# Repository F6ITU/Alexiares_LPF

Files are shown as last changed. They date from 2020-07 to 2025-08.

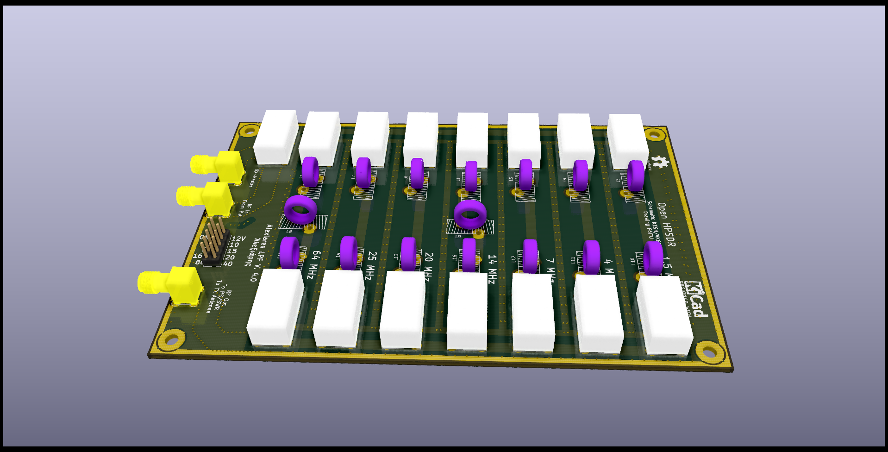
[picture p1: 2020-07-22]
images/LPF Up.png

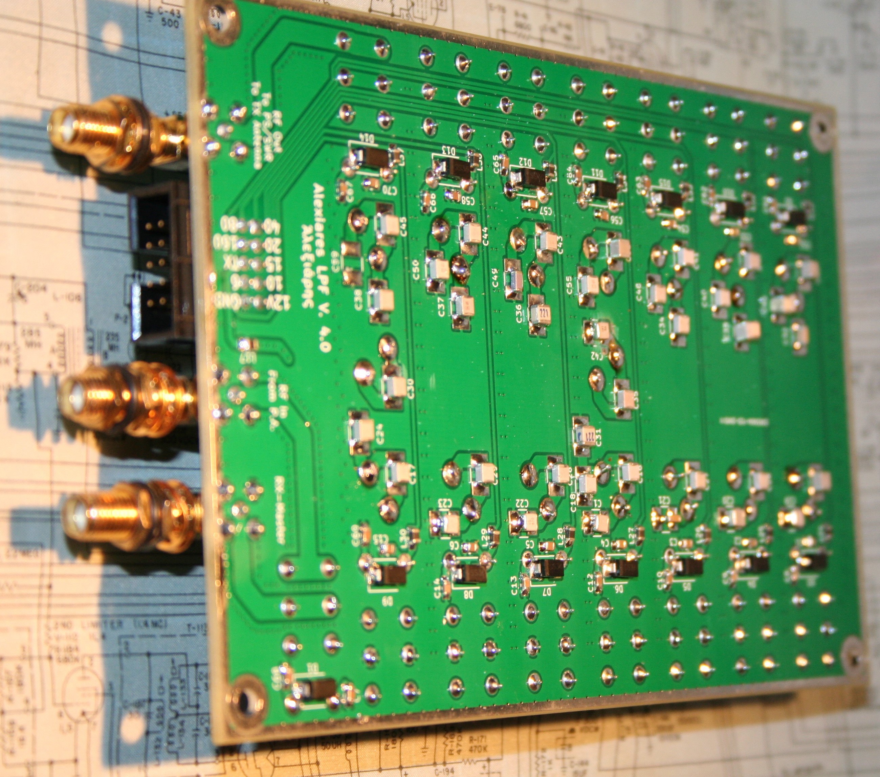
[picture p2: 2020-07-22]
images/IMG_8970.JPG

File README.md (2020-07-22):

# Alexiares_LPF
This repository contains the up to date version of the OpenHPSDR Low Pass Filter project(Alexiares frontend). 

**Important notice** : please check the "Branch" pull-down menu to see the different versions of the pcb

This work is protected by the TAPR Open Hardware Licence https://www.tapr.org/ohl.html

Original work by Graham Haddock, KE9H and Phil Harman, VK6APH.

3D image of the board are stored in the "images" folder (3D and pcb planes)

This folder also include "real life" pictures of the board, Vector Analyzer capture of the filter's characteristics and a pdf file of the schematic

Board's dimensions 10x15cm , 4 layers

So far, the Alex project under Kicad contains: 

AlexI2C

Alexandrie 

Alexiares_Coax_Out

Alexiares_HPF

Alexiares_LPF (this one)

Mentor

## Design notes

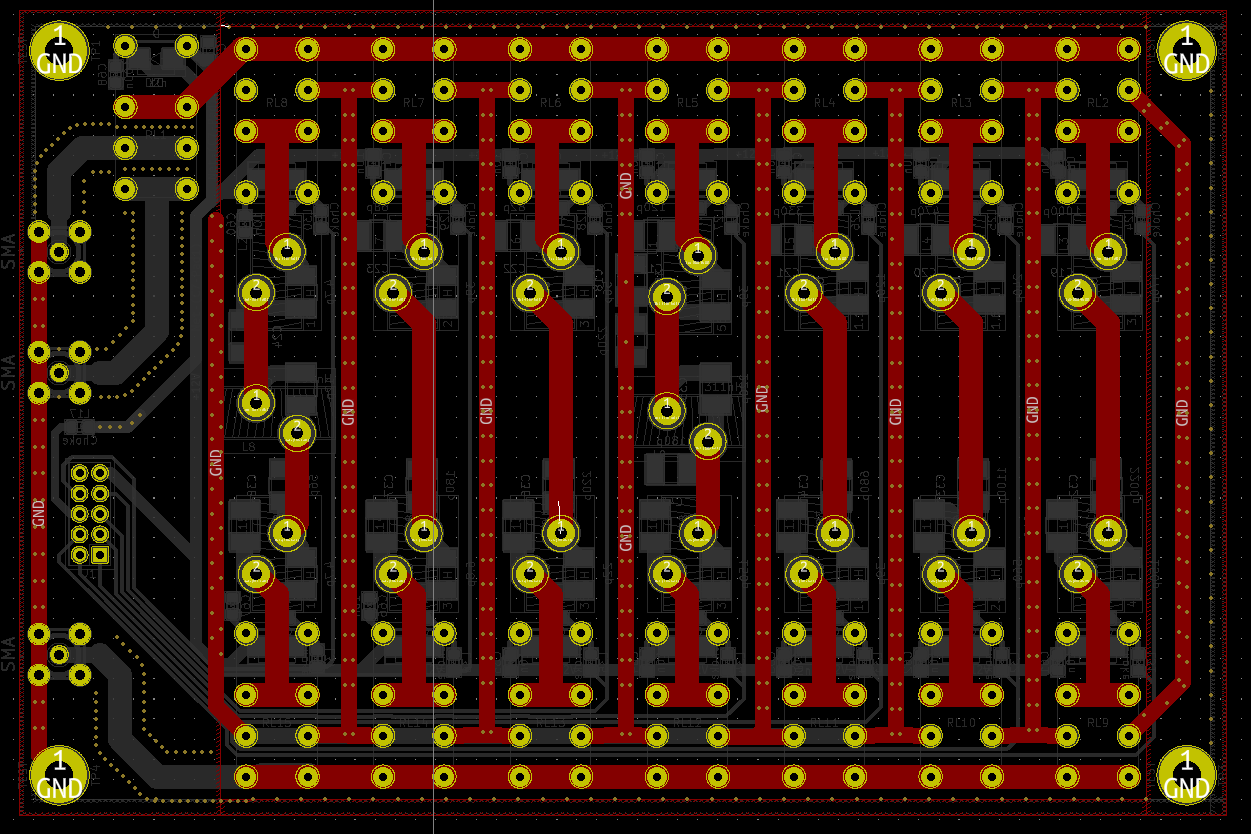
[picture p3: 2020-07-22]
images/dessus pistes.PNG

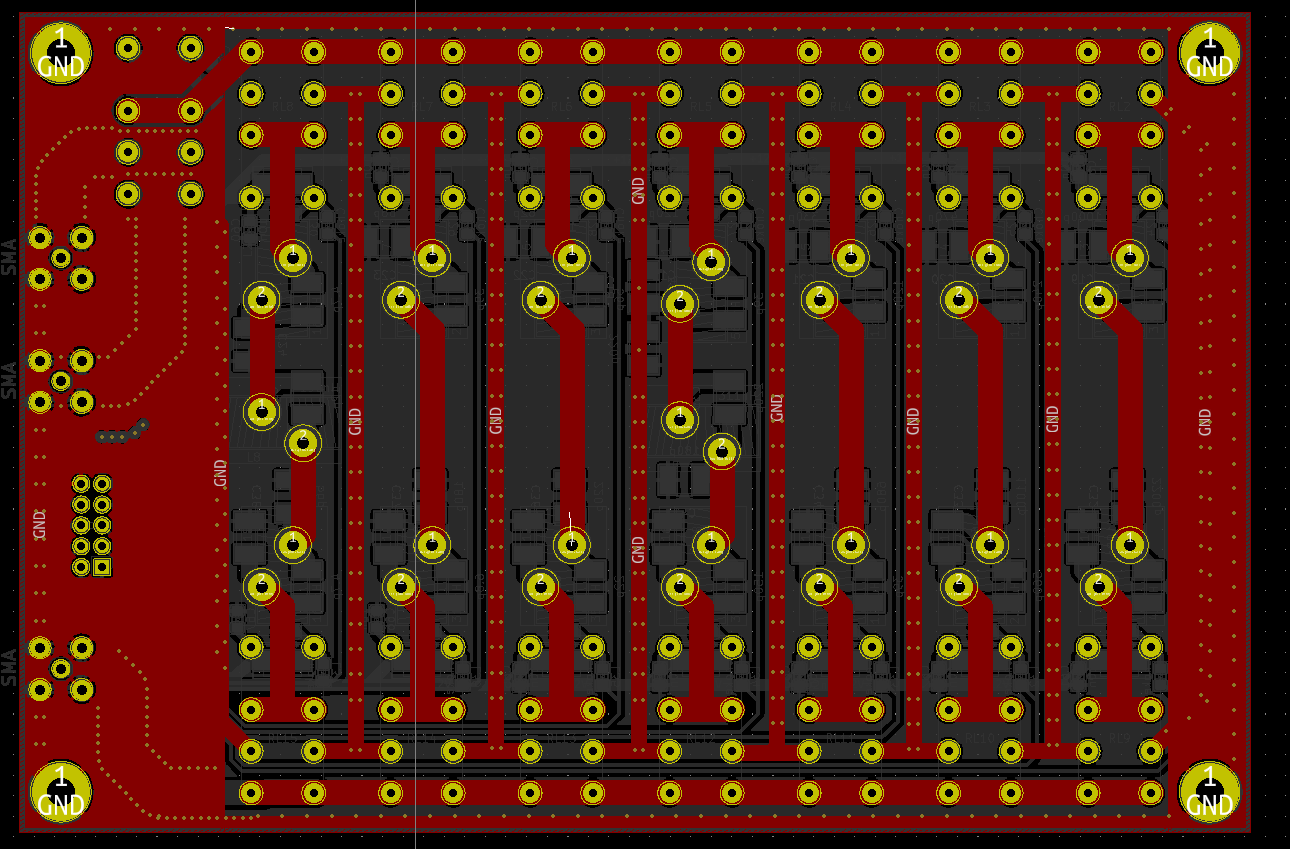
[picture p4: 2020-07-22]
images/dessus avec plan de masse.PNG

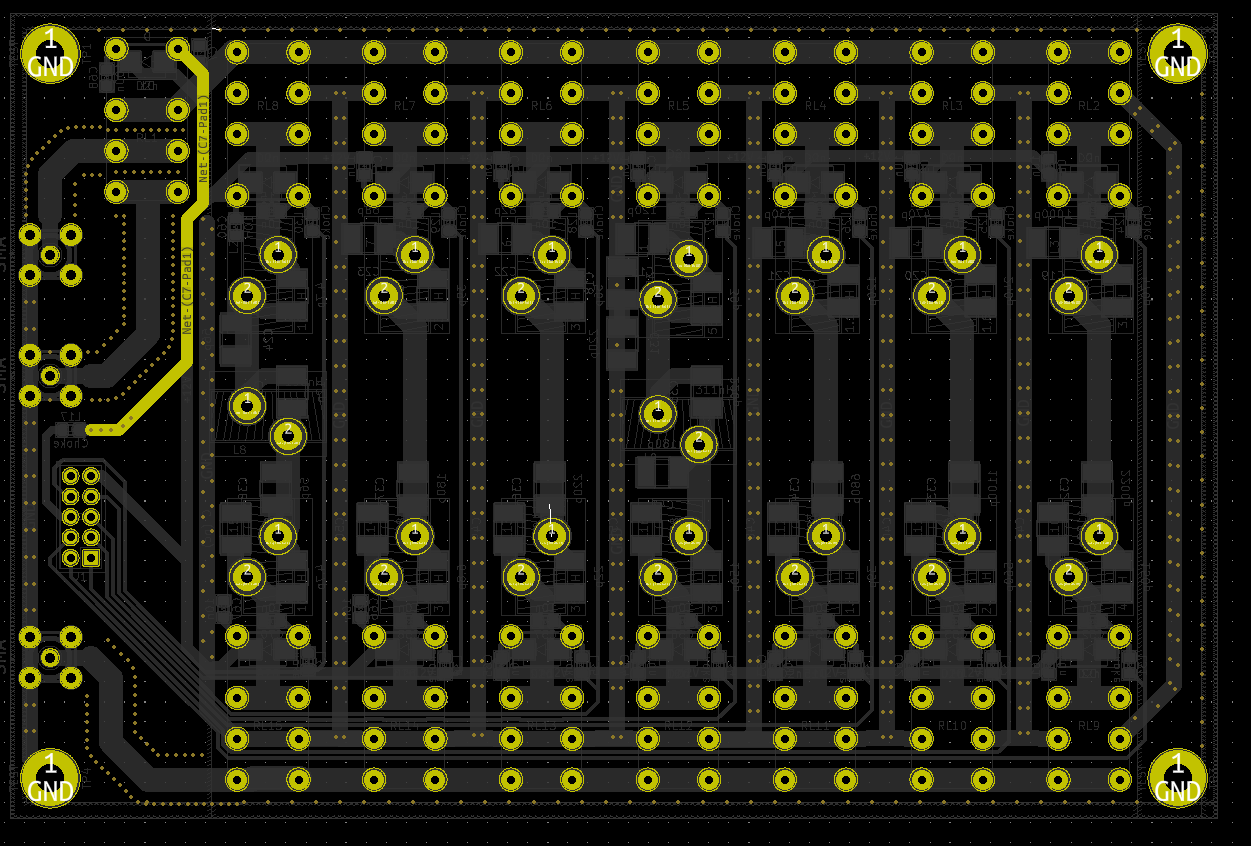
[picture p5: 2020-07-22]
images/layer 1TX-RX.PNG

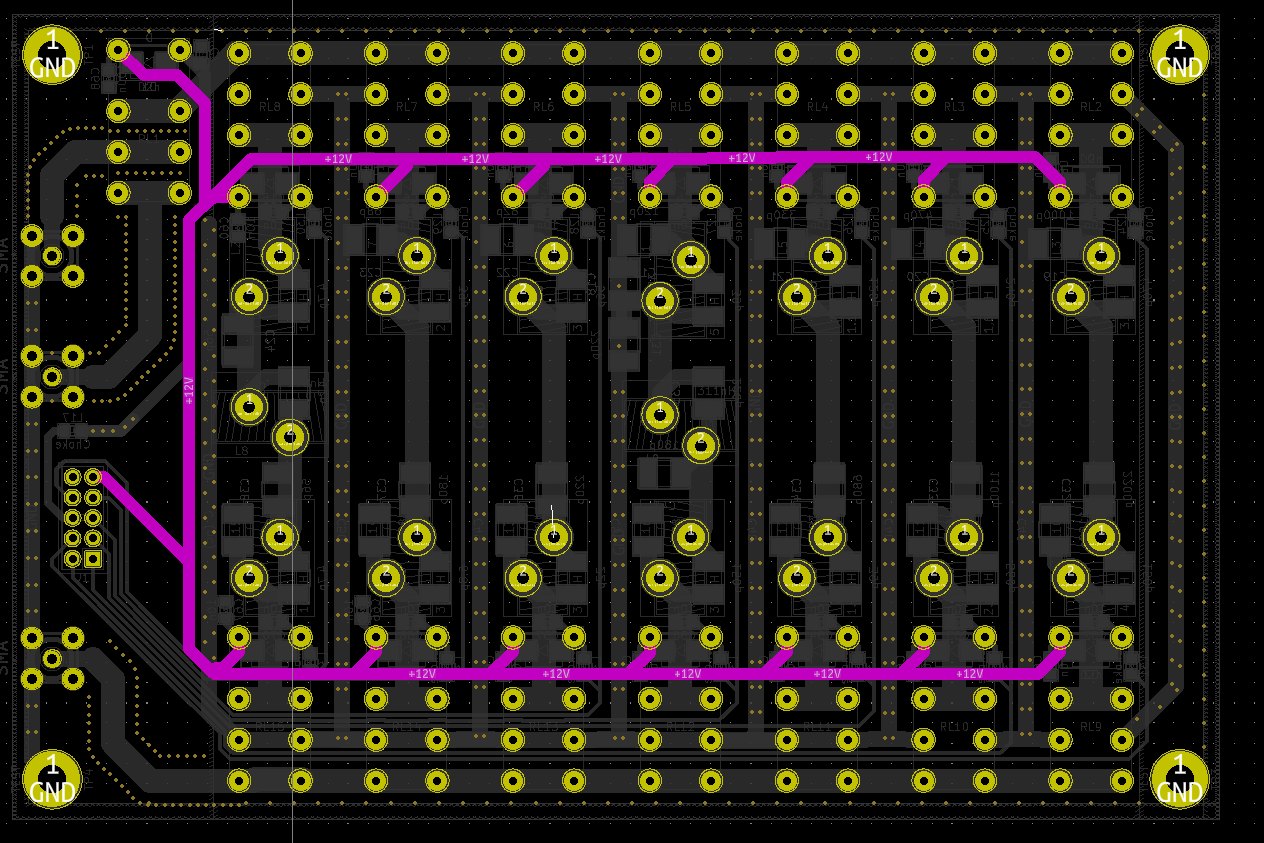
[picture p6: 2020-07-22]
images/layer 12V.PNG

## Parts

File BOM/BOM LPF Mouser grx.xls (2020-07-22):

Component Count: |  | 134
Ref | Qty | Value | Footprint | Manufacturer | Type | Vendor | Reference | Complement
C1-C10,C12-C15,C52-C54,C56-C58,C60-C67,C70 | 29 | 10n | Capacitor_SMD:C_0805_2012Metric_Pad1.15x1.40mm_HandSolder | Wurth Elektronik | MLCC | Mouser | 710-885012207092
C19 |  | 1000p | Johanson | johanson 1812 | MLCC 500V | Mouser | 501S43N102JV4E
C49 | 1 | 100p | Vishay HiFreq 1111 MLCC | Vishay Vitramon | MLCC 500V | Mouser | VJ1111D101JXLAJ
C33 | 1 | 1100p | Vishay HiFreq 1111 MLCC | Vishay Vitramon | MLCC 500V | Mouser | VJ1111D102KXDAT | VJ1111D101JXLAJ
C46 | 1 | 1100p | Vishay HiFreq 1111 MLCC | Vishay Vitramon | MLCC 500V | Mouser | VJ1111D102KXDAT | VJ1111D101JXLAJ
C11 | 1 | 120p | Vishay HiFreq 1111 MLCC | Vishay Vitramon | MLCC 500V | Mouser | VJ1111D121KXGAT
C27 | 1 | 120p | Vishay HiFreq 1111 MLCC | Vishay Vitramon | MLCC 500V | Mouser | VJ1111D121KXGAT
C30 | 1 | 12p | Vishay HiFreq 1111 MLCC | Vishay Vitramon | MLCC 500V | Mouser | VJ1111D120GLGQJ
C39 | 1 | 150p | Vishay HiFreq 1111 MLCC | Vishay Vitramon | MLCC 500V | Mouser | VJ1111D151GXLQJ
C51 | 1 | 150p | Vishay HiFreq 1111 MLCC | Vishay Vitramon | MLCC 500V | Mouser | VJ1111D151GXLQJ
C37 | 1 | 180p | Vishay HiFreq 1111 MLCC | Vishay Vitramon | MLCC 500V | Mouser | VJ1111D181JXLAJ
C42 | 1 | 180p | Vishay HiFreq 1111 MLCC | Vishay Vitramon | MLCC 500V | Mouser | VJ1111D181JXLAJ
C32 | 1 | 2200p | Johanson | Johanson 1812 | MLCC 1000V | Mouser | 102S43N222KV4E
C31 | 1 | 220p | Vishay HiFreq 1111 MLCC | Vishay Vitramon | MLCC 500V | Mouser | VJ1111D221JXLAJ
C35 | 1 | 220p | Vishay HiFreq 1111 MLCC | Vishay Vitramon | MLCC 500V | Mouser | VJ1111D221JXLAJ
C36 | 1 | 220p | Vishay HiFreq 1111 MLCC | Vishay Vitramon | MLCC 500V | Mouser | VJ1111D221JXLAJ
C43 | 1 | 22p | Vishay HiFreq 1111 MLCC | Vishay Vitramon | MLCC 500V | Mouser | VJ1111D220GLLQJ
C26 | 1 | 240p | Vishay HiFreq 1111 MLCC | Vishay Vitramon | MLCC 500V | Mouser | VJ1111D241JXLAJ
C21 | 1 | 330p | Vishay HiFreq 1111 MLCC | Vishay Vitramon | MLCC 500V | Mouser | VJ1111D331JXLAJ
C48 | 1 | 390p | Vishay HiFreq 1111 MLCC | Vishay Vitramon | MLCC 500V | Mouser | VJ1111D391KXLAJ
C16 | 1 | 39p | Vishay HiFreq 1111 MLCC | Vishay Vitramon | MLCC 500V | Mouser | VJ1111D390JXLAJ
C18 | 1 | 39p | Vishay HiFreq 1111 MLCC | Vishay Vitramon | MLCC 500V | Mouser | VJ1111D390JXLAJ
C29 | 1 | 39p | Vishay HiFreq 1111 MLCC | Vishay Vitramon | MLCC 500V | Mouser | VJ1111D390JXLAJ
C41 | 1 | 39p | Vishay HiFreq 1111 MLCC | Vishay Vitramon | MLCC 500V | Mouser | VJ1111D390JXLAJ
C17,C45 | 2 | 4.7p | Vishay HiFreq 1111 MLCC | Vishay Vitramon | MLCC 500V | Mouser | VJ1111D4R7BXLQJ
C20,C25 | 2 | 470p | Vishay HiFreq 1111 MLCC | Vishay Vitramon | MLCC 500V | Mouser | VJ1111D471KXLAJ
C47 | 1 | 560p | Johanson | Johanson 1210 | MLCC 500V | Mouser | 501S41N561KV4E
C24,C28,C38 | 3 | 56p | Vishay HiFreq 1111 MLCC | Vishay Vitramon | MLCC 500V | Mouser | VJ1111D560GXLQJ
C44 | 1 | 6.8p | Vishay HiFreq 1111 MLCC | Vishay Vitramon | MLCC 500V | Mouser | VJ1111D6R8BXGQJ
C34 | 1 | 680p | Johanson | johanson 1210 | MLCC 1000V | Mouser | 102S41N681KV4E
C23,C40 | 2 | 68p | Vishay HiFreq 1111 MLCC | Vishay Vitramon | MLCC 500V | Mouser | VJ1111D680GXLQJ
C22,C50 | 2 | 82p | Vishay HiFreq 1111 MLCC | Vishay Vitramon | MLCC 500V | Mouser | VJ1111D820GXGQJ
C55 | 1 | 82p | Capacitor_SMD:C_0805_2012Metric_Pad1.15x1.40mm_HandSolder | Wurth Elektronik | MLCC | Mouser | VJ1111D820GXGQJ
C59 | 0 | C (nc) | ATC_B:ATC_500_HandSoldering |  |  | DNI | DNI
C68 | 1 | 100n | Capacitor_SMD:C_0805_2012Metric_Pad1.15x1.40mm_HandSolder | Wurth Elektronik | MLCC | Mouser | 710-885012207098
D1-D15 | 15 | D | Diode_SMD:D_SMB | Comchip | Schottky SS24 (DO214) | Mouser | 750-SS24B-HF
J1 | 1 | Conn_02x05_Counter_Clockwise | Connector_PinHeader_2.54mm:PinHeader_2x05_P2.54mm_Vertical
L4 | 1 | 1,66uH | T50:T50_V_THT | Amidon | T68-2 | kitsandparts.com
L5 | 2 | 1.18uH | T50:T50_V_THT | Amidon | T68-2 | kitsandparts.com
L12 | 2 | 1.36uH | T50:T50_V_THT | Amidon | T68-2 | kitsandparts.com
L2,L15 | 2 | 169nH | T50:T50_V_THT | Amidon | T68-10 | Reichelt
L8 | 1 | 196nH | T50:T50_V_THT | Amidon | T68-10 | Reichelt
L11 | 1 | 2.02uH | T50:T50_V_THT | Amidon | T68-2 | kitsandparts.com
L7 | 1 | 235nH | T50:T50_V_THT | Amidon | T68-10 | Reichelt
L3 | 1 | 3.5uH | T50:T50_V_THT | Amidon | T68-1 | kitsandparts.com
L6,L9,L16 | 3 | 311nH | T50:T50_V_THT | Amidon | T68-6 | kitsandparts.com
L14 | 1 | 311nH | T50:T50_V_THT | Amidon | T68-10 | Reichelt
L13 | 1 | 351nH | T50:T50_V_THT | Amidon | T68-6 | kitsandparts.com
L10 | 1 | 4.4uH | T50:T50_V_THT | Amidon | T68-1 | kitsandparts.com
L1 | 1 | 562nH | T50:T50_V_THT | Amidon | T68-6 | kitsandparts.com
L17,L24-L37 | 15 | Choke | Inductor_SMD:L_0805_2012Metric_Pad1.15x1.40mm_HandSolder | Murata | Ferrite bead | Mouser | BLM21PG221SN1D
P1,P3,P4 | 3 | SMA | SMA_PINS:SMA_PINS
RL1-RL15 | 15 | D2n | 2_Form_C_Relay:D2n | TE Connectivity / Axicom | 2formC 12V relay, non latch. | Mouser | 655-1-1393793-3
Pse note that the exact reference of the decoupling caps and ferrites are not mandatory. Any kind of 10 nf and ferrite bead could be used

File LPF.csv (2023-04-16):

Reference | Value | Footprint | Datasheet
C1 | 10n | Capacitor_SMD:C_0805_2012Metric_Pad1.15x1.40mm_HandSolder
C2 | 10n | Capacitor_SMD:C_0805_2012Metric_Pad1.15x1.40mm_HandSolder
C3 | 10n | Capacitor_SMD:C_0805_2012Metric_Pad1.15x1.40mm_HandSolder
C4 | 10n | Capacitor_SMD:C_0805_2012Metric_Pad1.15x1.40mm_HandSolder
C5 | 10n | Capacitor_SMD:C_0805_2012Metric_Pad1.15x1.40mm_HandSolder
C6 | 10n | Capacitor_SMD:C_0805_2012Metric_Pad1.15x1.40mm_HandSolder
C7 | 10n | Capacitor_SMD:C_0805_2012Metric_Pad1.15x1.40mm_HandSolder
C8 | 10n | Capacitor_SMD:C_0805_2012Metric_Pad1.15x1.40mm_HandSolder
C9 | 10n | Capacitor_SMD:C_0805_2012Metric_Pad1.15x1.40mm_HandSolder
C10 | 10n | Capacitor_SMD:C_0805_2012Metric_Pad1.15x1.40mm_HandSolder
C11 | 120p | ATC_B:ATC_500_HandSoldering
C12 | 10n | Capacitor_SMD:C_0805_2012Metric_Pad1.15x1.40mm_HandSolder
C13 | 10n | Capacitor_SMD:C_0805_2012Metric_Pad1.15x1.40mm_HandSolder
C14 | 10n | Capacitor_SMD:C_0805_2012Metric_Pad1.15x1.40mm_HandSolder
C15 | 10n | Capacitor_SMD:C_0805_2012Metric_Pad1.15x1.40mm_HandSolder
C16 | 39p | ATC_B:ATC_500_HandSoldering
C17 | 4.7p | ATC_B:ATC_500_HandSoldering
C18 | 39p | ATC_B:ATC_500_HandSoldering
C19 | 1000p | ATC_B:ATC_500_HandSoldering
C20 | 470p | ATC_B:ATC_500_HandSoldering
C21 | 330p | ATC_B:ATC_500_HandSoldering
C22 | 82p | ATC_B:ATC_500_HandSoldering
C23 | 68p | ATC_B:ATC_500_HandSoldering
C24 | 56p | ATC_B:ATC_500_HandSoldering
C25 | 470p | ATC_B:ATC_500_HandSoldering
C26 | 240p | ATC_B:ATC_500_HandSoldering
C27 | 120p | ATC_B:ATC_500_HandSoldering
C28 | 56p | ATC_B:ATC_500_HandSoldering
C29 | 39p | ATC_B:ATC_500_HandSoldering
C30 | 12p | ATC_B:ATC_500_HandSoldering
C31 | 220p | ATC_B:ATC_500_HandSoldering
C32 | 2200p | ATC_B:ATC_500_HandSoldering
C33 | 1100p | ATC_B:ATC_500_HandSoldering
C34 | 680p | ATC_B:ATC_500_HandSoldering
C35 | 220p | ATC_B:ATC_500_HandSoldering
C36 | 220p | ATC_B:ATC_500_HandSoldering
C37 | 180p | ATC_B:ATC_500_HandSoldering
C38 | 56p | ATC_B:ATC_500_HandSoldering
C39 | 150p | ATC_B:ATC_500_HandSoldering
C40 | 68p | ATC_B:ATC_500_HandSoldering
C41 | 39p | ATC_B:ATC_500_HandSoldering
C42 | 180p | ATC_B:ATC_500_HandSoldering
C43 | 22p | ATC_B:ATC_500_HandSoldering
C44 | 6.8p | ATC_B:ATC_500_HandSoldering
C45 | 4.7p | ATC_B:ATC_500_HandSoldering
C46 | 1100p | ATC_B:ATC_500_HandSoldering
C47 | 560p | ATC_B:ATC_500_HandSoldering
C48 | 390p | ATC_B:ATC_500_HandSoldering
C49 | 100p | ATC_B:ATC_500_HandSoldering
C50 | 82p | ATC_B:ATC_500_HandSoldering
C51 | 150p | ATC_B:ATC_500_HandSoldering
C52 | 10n | Capacitor_SMD:C_0805_2012Metric_Pad1.15x1.40mm_HandSolder
C53 | 10n | Capacitor_SMD:C_0805_2012Metric_Pad1.15x1.40mm_HandSolder
C54 | 10n | Capacitor_SMD:C_0805_2012Metric_Pad1.15x1.40mm_HandSolder
C55 | 82p | ATC_B:ATC_500_HandSoldering
C56 | 10n | Capacitor_SMD:C_0805_2012Metric_Pad1.15x1.40mm_HandSolder
C57 | 10n | Capacitor_SMD:C_0805_2012Metric_Pad1.15x1.40mm_HandSolder
C58 | 10n | Capacitor_SMD:C_0805_2012Metric_Pad1.15x1.40mm_HandSolder
C59 | C (nc) | ATC_B:ATC_500_HandSoldering
C60 | 10n | Capacitor_SMD:C_0805_2012Metric_Pad1.15x1.40mm_HandSolder
C61 | 10n | Capacitor_SMD:C_0805_2012Metric_Pad1.15x1.40mm_HandSolder
C62 | 10n | Capacitor_SMD:C_0805_2012Metric_Pad1.15x1.40mm_HandSolder
C63 | 10n | Capacitor_SMD:C_0805_2012Metric_Pad1.15x1.40mm_HandSolder
C64 | 10n | Capacitor_SMD:C_0805_2012Metric_Pad1.15x1.40mm_HandSolder
C65 | 10n | Capacitor_SMD:C_0805_2012Metric_Pad1.15x1.40mm_HandSolder
C66 | 10n | Capacitor_SMD:C_0805_2012Metric_Pad1.15x1.40mm_HandSolder
C67 | 10n | Capacitor_SMD:C_0805_2012Metric_Pad1.15x1.40mm_HandSolder
C68 | 100n | Capacitor_SMD:C_0805_2012Metric_Pad1.15x1.40mm_HandSolder
C70 | 10n | Capacitor_SMD:C_0805_2012Metric_Pad1.15x1.40mm_HandSolder
D1 | D | Diode_SMD:D_SMB
D2 | D | Diode_SMD:D_SMB
D3 | D | Diode_SMD:D_SMB
D4 | D | Diode_SMD:D_SMB
D5 | D | Diode_SMD:D_SMB
D6 | D | Diode_SMD:D_SMB
D7 | D | Diode_SMD:D_SMB
D8 | D | Diode_SMD:D_SMB
D9 | D | Diode_SMD:D_SMB
D10 | D | Diode_SMD:D_SMB
D11 | D | Diode_SMD:D_SMB
D12 | D | Diode_SMD:D_SMB
D13 | D | Diode_SMD:D_SMB
D14 | D | Diode_SMD:D_SMB
D15 | D | Diode_SMD:D_SMB
J1 | Conn_02x05_Counter_Clockwise | Connector_PinHeader_2.54mm:PinHeader_2x05_P2.54mm_Vertical
L1 | 562nH | T50:T50_V_THT
L2 | 169nH | T50:T50_V_THT
L3 | 3.5uH | T50:T50_V_THT
L4 | 1,66uH | T50:T50_V_THT
L5 | 1.18uH | T50:T50_V_THT
L6 | 311nH | T50:T50_V_THT
L7 | 235nH | T50:T50_V_THT
L8 | 196nH | T50:T50_V_THT
L9 | 311nH | T50:T50_V_THT
L10 | 4.4uH | T50:T50_V_THT
L11 | 2.02uH | T50:T50_V_THT
L12 | 1.36uH | T50:T50_V_THT
L13 | 351nH | T50:T50_V_THT
L14 | 311nH | T50:T50_V_THT
L15 | 169nH | T50:T50_V_THT
L16 | 311nH | T50:T50_V_THT
L17 | Choke | Inductor_SMD:L_0805_2012Metric_Pad1.15x1.40mm_HandSolder
L24 | Choke | Inductor_SMD:L_0805_2012Metric_Pad1.15x1.40mm_HandSolder
L25 | Choke | Inductor_SMD:L_0805_2012Metric_Pad1.15x1.40mm_HandSolder
L26 | Choke | Inductor_SMD:L_0805_2012Metric_Pad1.15x1.40mm_HandSolder
L27 | Choke | Inductor_SMD:L_0805_2012Metric_Pad1.15x1.40mm_HandSolder
L28 | Choke | Inductor_SMD:L_0805_2012Metric_Pad1.15x1.40mm_HandSolder
L29 | Choke | Inductor_SMD:L_0805_2012Metric_Pad1.15x1.40mm_HandSolder
L30 | Choke | Inductor_SMD:L_0805_2012Metric_Pad1.15x1.40mm_HandSolder
L31 | Choke | Inductor_SMD:L_0805_2012Metric_Pad1.15x1.40mm_HandSolder
L32 | Choke | Inductor_SMD:L_0805_2012Metric_Pad1.15x1.40mm_HandSolder
L33 | Choke | Inductor_SMD:L_0805_2012Metric_Pad1.15x1.40mm_HandSolder
L34 | Choke | Inductor_SMD:L_0805_2012Metric_Pad1.15x1.40mm_HandSolder
L35 | Choke | Inductor_SMD:L_0805_2012Metric_Pad1.15x1.40mm_HandSolder
L36 | Choke | Inductor_SMD:L_0805_2012Metric_Pad1.15x1.40mm_HandSolder
L37 | Choke | Inductor_SMD:L_0805_2012Metric_Pad1.15x1.40mm_HandSolder
P1 | SMA | SMA_PINS:SMA_PINS
P3 | SMA | SMA_PINS:SMA_PINS
P4 | SMA | SMA_PINS:SMA_PINS
RL1 | D2n | 2_Form_C_Relay:D2n
RL2 | D2n | 2_Form_C_Relay:D2n
RL3 | D2n | 2_Form_C_Relay:D2n
RL4 | D2n | 2_Form_C_Relay:D2n
RL5 | D2n | 2_Form_C_Relay:D2n
RL6 | D2n | 2_Form_C_Relay:D2n
RL7 | D2n | 2_Form_C_Relay:D2n
RL8 | D2n | 2_Form_C_Relay:D2n
RL9 | D2n | 2_Form_C_Relay:D2n
RL10 | D2n | 2_Form_C_Relay:D2n
RL11 | D2n | 2_Form_C_Relay:D2n
RL12 | D2n | 2_Form_C_Relay:D2n
RL13 | D2n | 2_Form_C_Relay:D2n
RL14 | D2n | 2_Form_C_Relay:D2n
RL15 | D2n | 2_Form_C_Relay:D2n
TP1 | TEST | MountingHole:MountingHole_3.5mm_Pad
TP2 | TEST | MountingHole:MountingHole_3.5mm_Pad
TP3 | TEST | MountingHole:MountingHole_3.5mm_Pad
TP4 | TEST | MountingHole:MountingHole_3.5mm_Pad

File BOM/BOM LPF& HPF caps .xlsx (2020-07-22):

LPF
Ref | Qty | Value(pf) | type | Ref Farnell | Format | Brand | Qty | toroids | Qty
C17, C45 | 2 | 4.7 | ATC/AQ13 | 2420129 | 1111 |  | 10 | T68-1
C44, | 1 | 6.8 | ATC/AQ13 | 2420131 |  |  | " | T68-2
C30, | 1 | 12 | ATC/AQ13 | 2420135 |  |  |  | T68-6
C69, | 1 | 18 | ATC/AQ13 | 2420137 | 1111 |  |  | T68-10
C43, | 1 | 22 | ATC/AQ13 | 2420139
C41, C29, C16, C18, | 4 | 39 | ATC/AQ13 | 2420145 |  | 8
C38, C24, C28, | 3 | 56 | ATC/AQ13 | 2420147 |  | 6
C40, C23, | 2 | 68 | ATC/AQ13 | 2420148
C55, C22, C50, | 3 | 82 | ATC/AQ13 | 2420149
C49, | 1 | 100 | ATC/AQ13 | 2420150
C27, C11, | 2 | 120 | ATC/AQ13 | 2420151
C39, C51, | 2 | 150 | ATC/AQ13 | 2420152
C42, C37, | 2 | 180 | ATC/AQ13 |  |  | ??? Non | 100+82
C35, C31, C36, | 3 | 220 | ATC/AQ13 | 2420155
C26, | 1 | 240 | ATC/AQ13 | 2420157
C21, | 1 | 330 | ATC/AQ13 | 2420142 |  | 2420159 | 300+30 (x2
C48, | 1 | 390 | ATC/AQ13 | 2420161
C25, C20, | 2 | 470 | ATC/AQ13 | 2420162
C47, | 1 | 560 | ATC/AQ13 | 2420163
C34, | 1 | 680 | ATC/AQ13 | 2420164 | 1111
C19, | 1 | 1000 | ATC/AQ13 | 2420167 | 1111
C46, C33, | 2 | 1100 | ATC/AQ13
C32, | 1 | 2200 | ATC/AQ13 | 2420172 |  |  | 1200 pf pour complétion
Total | 37
HPF
Ref | Qty | Val | Footprint | Material
C101, | 1 | 1.2n | 1206 | Multilayer NP0/C0G |  |  |  | toroids | Qty
C121, | 1 | 100p | 1206 | Multilayer NP0/C0G |  |  |  | T50-2 | 6
C125, | 1 | 1n | 1206 | Multilayer NP0/C0G |  |  |  | T50-6 | 9
C134, | 1 | 680p | 1206 | Multilayer NP0/C0G
C147, | 1 | 68pC | 1206 | Multilayer NP0/C0G
C123, C111, | 2 | 33p | 1206 | Multilayer NP0/C0G
C128, C140, | 2 | 68p | 1206 | Multilayer NP0/C0G
C130, C122, | 2 | 47p | 1206 | Multilayer NP0/C0G
C131, C113, | 2 | 120p | 1206 | Multilayer NP0/C0G
C132, C108, | 2 | 22p | 1206 | Multilayer NP0/C0G
C136, C126, | 2 | 390p | 1206 | Multilayer NP0/C0G
C145, C91, | 2 | 820p | 1206 | Multilayer NP0/C0G
C146, C124, | 2 | 680p | 1206 | Multilayer NP0/C0G
C149, C92, | 2 | 470p | 1206 | Multilayer NP0/C0G
C93, C116, C109, | 3 | 330p | 1206 | Multilayer NP0/C0G
C100, C115, C106, | 3 | 1.5n | 1206 | Multilayer NP0/C0G
C117, C137, C139, | 3 | 270p | 1206 | Multilayer NP0/C0G
C129, C112, C120, | 3 | 180p | 1206 | Multilayer NP0/C0G
C148, C135, C119, | 3 | 560p | 1206 | Multilayer NP0/C0G
C98, C143, C144, C133, | 4 | 1.8n | 1206 | Multilayer NP0/C0G
C97, C107, C102, C96, C95, C183, | 6 | 2.2n | 1206 | Multilayer NP0/C0G
C118, C94, C127, C110, C104, C103, | 6 | 220p | 1206 | Multilayer NP0/C0G

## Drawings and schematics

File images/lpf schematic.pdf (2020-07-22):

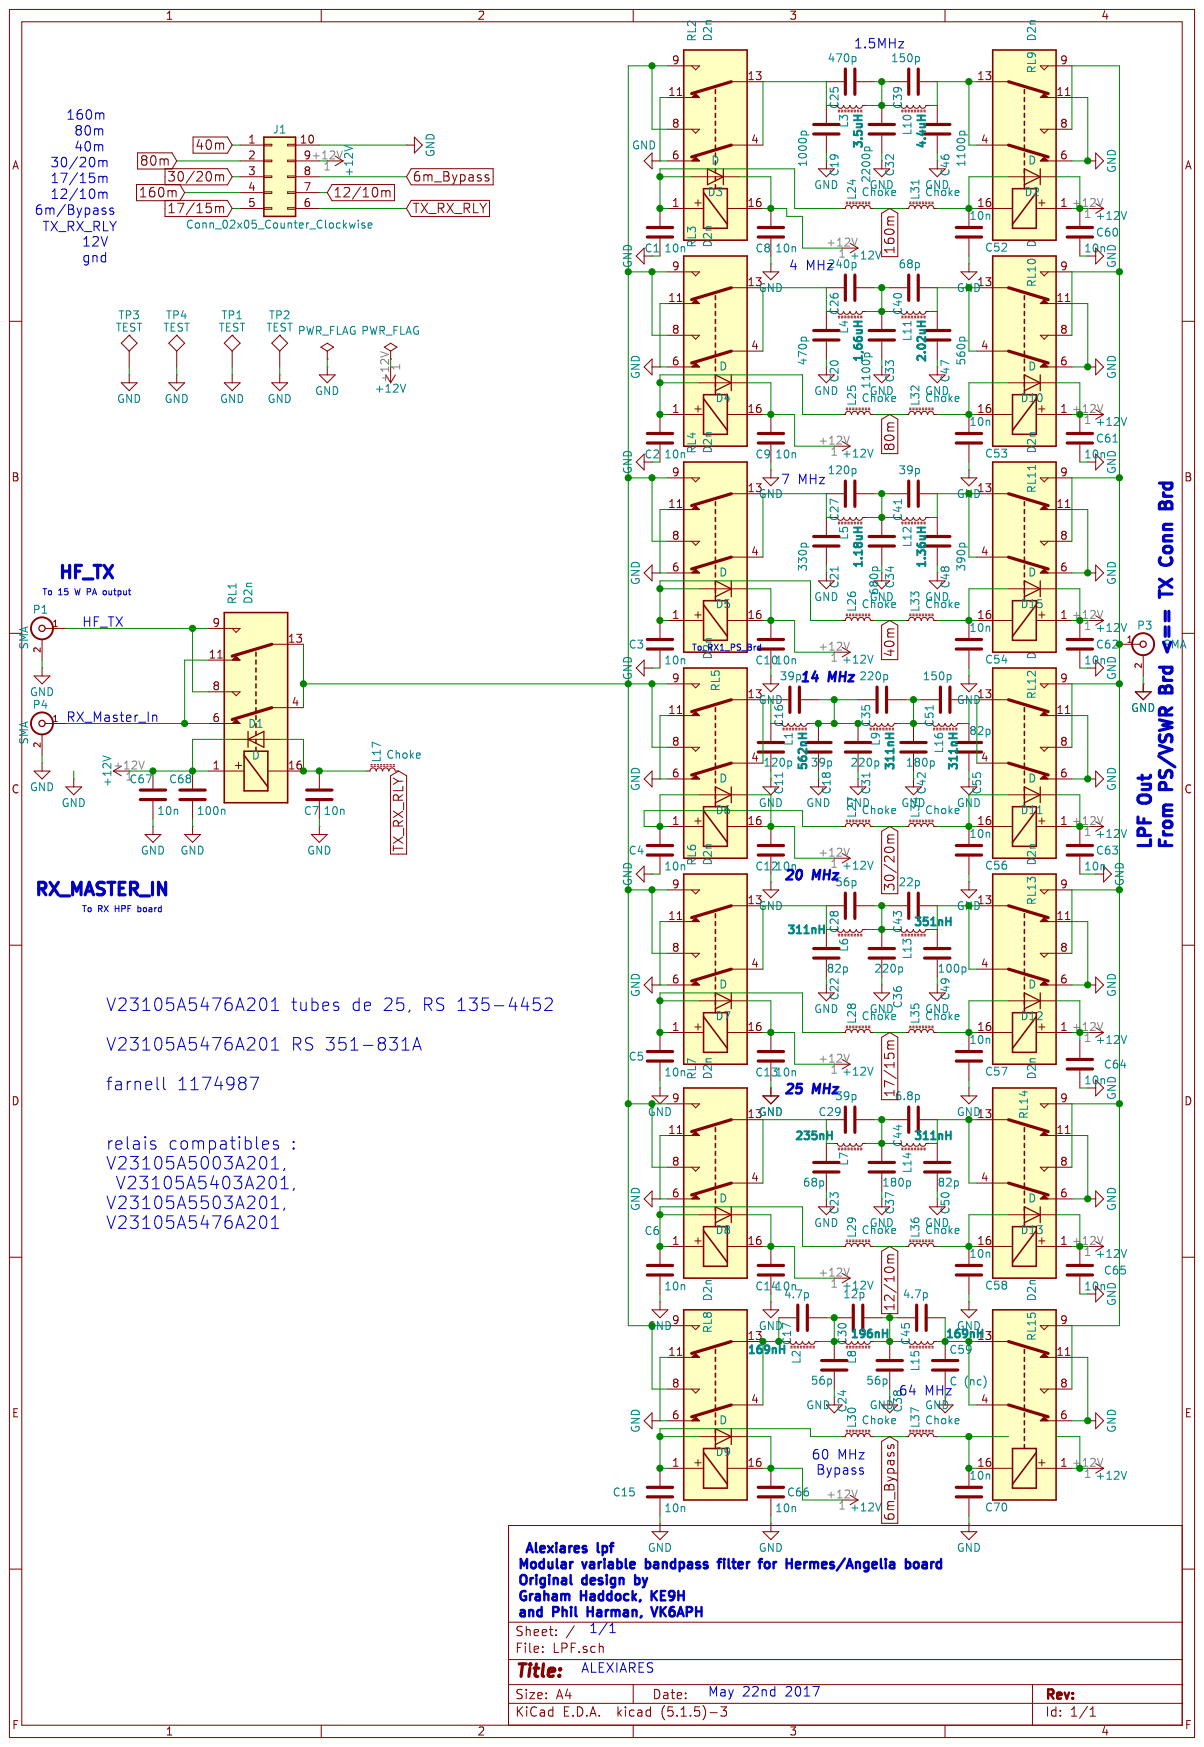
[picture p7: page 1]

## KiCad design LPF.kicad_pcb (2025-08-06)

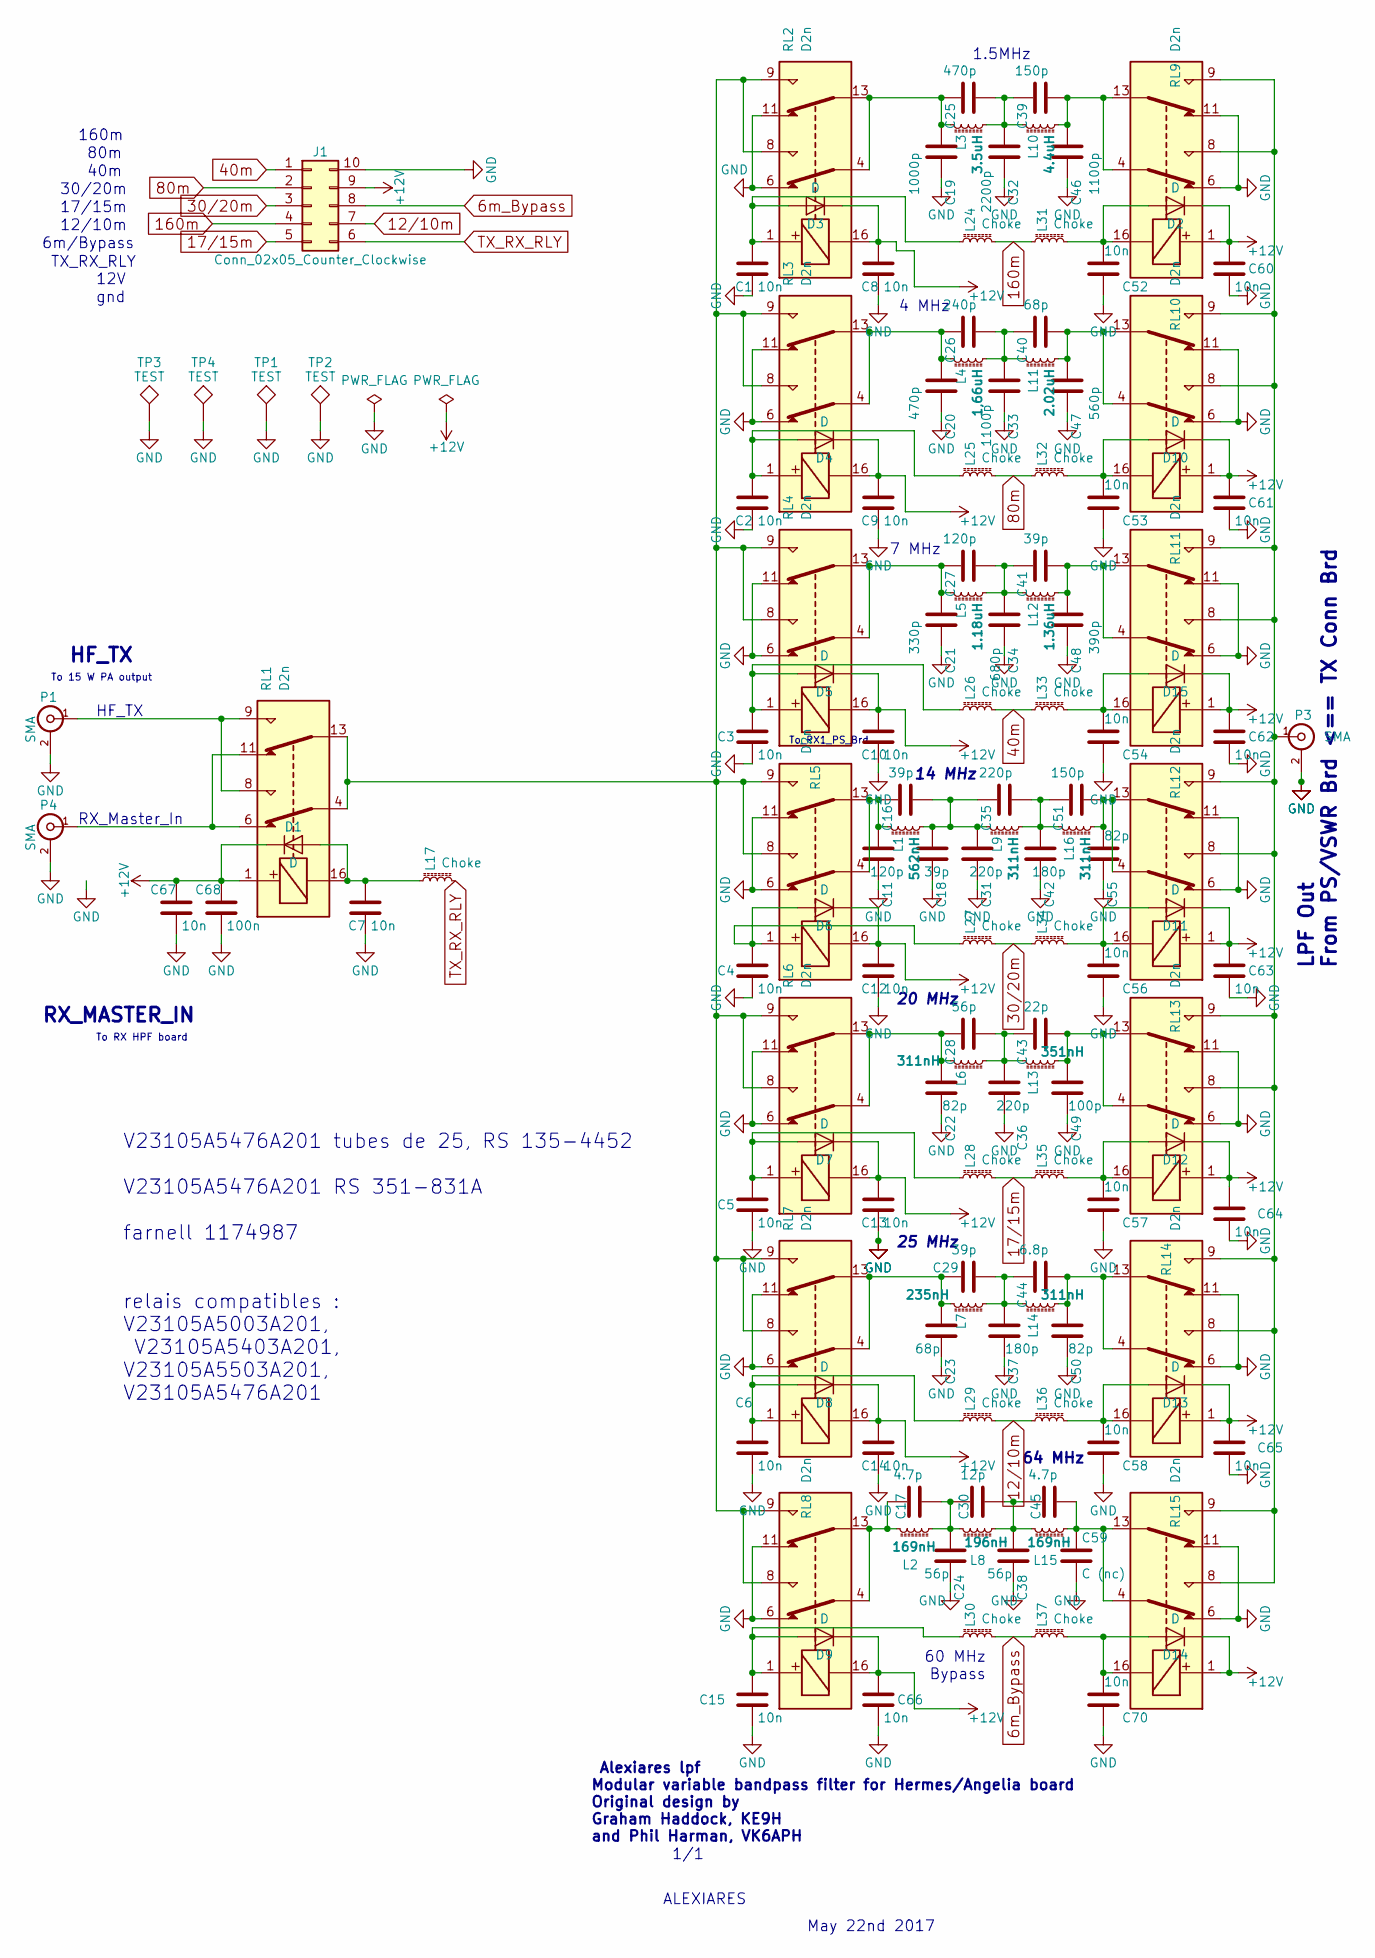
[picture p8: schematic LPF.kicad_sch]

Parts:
C1, C2, C3, C4, C5, C6, C7, C8, C9, C10, C12, C13, C14, C15, C52, C53, C54, C56, C57, C58, C60, C61, C62, C63, C64, C65, C66, C67, C70: 10n; C_0805_2012Metric_Pad1.15x1.40mm_HandSolder
C11, C27: 120p; ATC_500_HandSoldering
C16, C18, C29, C41: 39p; ATC_500_HandSoldering
C17, C45: 4.7p; ATC_500_HandSoldering
C19: 1000p; ATC_500_HandSoldering
C20, C25: 470p; ATC_500_HandSoldering
C21: 330p; ATC_500_HandSoldering
C22, C50, C55: 82p; ATC_500_HandSoldering
C23, C40: 68p; ATC_500_HandSoldering
C24, C28, C38: 56p; ATC_500_HandSoldering
C26: 240p; ATC_500_HandSoldering
C30: 12p; ATC_500_HandSoldering
C31, C35, C36: 220p; ATC_500_HandSoldering
C32: 2200p; ATC_500_HandSoldering
C33, C46: 1100p; ATC_500_HandSoldering
C34: 680p; ATC_500_HandSoldering
C37, C42: 180p; ATC_500_HandSoldering
C39, C51: 150p; ATC_500_HandSoldering
C43: 22p; ATC_500_HandSoldering
C44: 6.8p; ATC_500_HandSoldering
C47: 560p; ATC_500_HandSoldering
C48: 390p; ATC_500_HandSoldering
C49: 100p; ATC_500_HandSoldering
C59: C (nc); ATC_500_HandSoldering
C68: 100n; C_0805_2012Metric_Pad1.15x1.40mm_HandSolder
D1, D2, D3, D4, D5, D6, D7, D8, D9, D10, D11, D12, D13, D14, D15: D; D_SMB
J1: Conn_02x05_Counter_Clockwise; PinHeader_2x05_P2.54mm_Vertical
L1: 562nH; T50_V_THT
L2, L15: 169nH; T50_V_THT
L3: 3.5uH; T50_V_THT
L4: 1,66uH; T50_V_THT
L5: 1.18uH; T50_V_THT
L6, L9, L14, L16: 311nH; T50_V_THT
L7: 235nH; T50_V_THT
L8: 196nH; T50_V_THT
L10: 4.4uH; T50_V_THT
L11: 2.02uH; T50_V_THT
L12: 1.36uH; T50_V_THT
L13: 351nH; T50_V_THT
L17, L24, L25, L26, L27, L28, L29, L30, L31, L32, L33, L34, L35, L36, L37: Choke; L_0805_2012Metric_Pad1.15x1.40mm_HandSolder
P1, P3, P4: SMA; SMA_PINS
RL1, RL2, RL3, RL4, RL5, RL6, RL7, RL8, RL9, RL10, RL11, RL12, RL13, RL14, RL15: D2n
TP1, TP2, TP3, TP4: TEST; MountingHole_3.5mm_Pad

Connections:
6m_Bypass: J1.8, L30.2, L37.1
12/10m: J1.7, L29.2, L36.1
17/15m: J1.5, L28.2, L35.1
30/20m: J1.3, L27.2, L34.1
40m: J1.1, L26.2, L33.1
80m: J1.2, L25.2, L32.1
160m: J1.4, L24.2, L31.1
+12V: C8.1, C9.1, C10.1, C12.1, C13.1, C14.1, C60.1, C61.1, C62.1, C63.1, C64.1, C65.1, C66.1, C67.1, C68.1, D1.1 (K), D2.1 (K), D3.1 (K), D4.1 (K), D5.1 (K), D6.1 (K), D7.1 (K), D8.1 (K), D9.1 (K), D10.1 (K), D11.1 (K), D12.1 (K), D13.1 (K), D14.1 (K), D15.1 (K), J1.9, RL1.1, RL2.16, RL3.16, RL4.16, RL5.16, RL6.16, RL7.16, RL8.16, RL9.1, RL10.1, RL11.1, RL12.1, RL13.1, RL14.1, RL15.1
GND: C1.2, C2.2, C3.2, C4.2, C5.2, C6.2, C7.2, C8.2, C9.2, C10.2, C11.1, C12.2, C13.2, C14.2, C15.2, C18.1, C19.1, C20.1, C21.1, C22.1, C23.1, C24.1, C31.1, C32.1, C33.1, C34.1, C36.1, C37.1, C38.1, C42.1, C46.1, C47.1, C48.1, C49.1, C50.1, C52.1, C53.1, C54.1, C55.1, C56.1, C57.1, C58.1, C59.2, C60.2, C61.2, C62.2, C63.2, C64.2, C65.2, C66.2, C67.2, C68.2, C70.1, J1.10, P1.2 (Ext), P3.2 (Ext), P4.2 (Ext), RL2.6, RL2.11, RL3.6, RL3.11, RL4.6, RL4.11, RL5.6, RL5.11, RL6.6, RL6.11, RL7.6, RL7.11, RL8.6, RL8.11, RL9.6, RL9.11, RL10.6, RL10.11, RL11.6, RL11.11, RL12.6, RL12.11, RL13.6, RL13.11, RL14.6, RL14.11, RL15.6, RL15.11, TP1.1, TP2.1, TP3.1, TP4.1
unnamed: C1.1, D3.2 (A), L24.1, RL2.1
unnamed: C2.1, D4.2 (A), L25.1, RL3.1
unnamed: C3.1, D5.2 (A), L26.1, RL4.1
unnamed: C4.1, D6.2 (A), L27.1, RL5.1
unnamed: C5.1, D7.2 (A), L28.1, RL6.1
unnamed: C6.1, D8.2 (A), L29.1, RL7.1
unnamed: C7.1, D1.2 (A), L17.1, RL1.16
unnamed: C11.2, C16.1, L1.1, RL5.4, RL5.13
unnamed: C15.1, D9.2 (A), L30.1, RL8.1
unnamed: C16.2, C18.2, C31.2, C35.1, L1.2, L9.1
unnamed: C17.1, L2.1, RL8.4, RL8.13
unnamed: C17.2, C24.2, C30.1, L2.2, L8.1
unnamed: C19.2, C25.1, L3.1, RL2.4, RL2.13
unnamed: C20.2, C26.1, L4.1, RL3.4, RL3.13
unnamed: C21.2, C27.1, L5.1, RL4.4, RL4.13
unnamed: C22.2, C28.1, L6.1, RL6.4, RL6.13
unnamed: C23.2, C29.1, L7.1, RL7.4, RL7.13
unnamed: C25.2, C32.2, C39.1, L3.2, L10.1
unnamed: C26.2, C33.2, C40.1, L4.2, L11.1
unnamed: C27.2, C34.2, C41.1, L5.2, L12.1
unnamed: C28.2, C36.2, C43.1, L6.2, L13.1
unnamed: C29.2, C37.2, C44.1, L7.2, L14.1
unnamed: C30.2, C38.2, C45.1, L8.2, L15.1
unnamed: C35.2, C42.2, C51.1, L9.2, L16.1
unnamed: C39.2, C46.2, L10.2, RL9.4, RL9.13
unnamed: C40.2, C47.2, L11.2, RL10.4, RL10.13
unnamed: C41.2, C48.2, L12.2, RL11.4, RL11.13
unnamed: C43.2, C49.2, L13.2, RL13.4, RL13.13
unnamed: C44.2, C50.2, L14.2, RL14.4, RL14.13
unnamed: C45.2, C59.1, L15.2, RL15.4, RL15.13
unnamed: C51.2, C55.2, L16.2, RL12.4, RL12.13
unnamed: C52.2, D2.2 (A), L31.2, RL9.16
unnamed: C53.2, D10.2 (A), L32.2, RL10.16
unnamed: C54.2, D15.2 (A), L33.2, RL11.16
unnamed: C56.2, D11.2 (A), L34.2, RL12.16
unnamed: C57.2, D12.2 (A), L35.2, RL13.16
unnamed: C58.2, D13.2 (A), L36.2, RL14.16
unnamed: C70.2, D14.2 (A), L37.2, RL15.16
unnamed: P1.1 (In), RL1.8, RL1.9
unnamed: P3.1 (In), RL9.8, RL9.9, RL10.8, RL10.9, RL11.8, RL11.9, RL12.8, RL12.9, RL13.8, RL13.9, RL14.8, RL14.9, RL15.8, RL15.9
unnamed: P4.1 (In), RL1.6, RL1.11
unnamed: RL1.4, RL1.13, RL2.8, RL2.9, RL3.8, RL3.9, RL4.8, RL4.9, RL5.8, RL5.9, RL6.8, RL6.9, RL7.8, RL7.9, RL8.8, RL8.9
TX_RX_RLY: J1.6, L17.2

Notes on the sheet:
gnd
25 MHz
30/20m
TX_RX_RLY
12V
ALEXIARES
160m
6m/Bypass
1/1
14 MHz
4 MHz
80m
V23105A5476A201 tubes de 25, RS 135-4452 V23105A5476A201 RS 351-831A farnell 1174987 relais compatibles : V23105A5003A201, V23105A5403A201, V23105A5503A201, V23105A5476A201
To_RX1_PS_Brd
17/15m
To 15 W PA output
1.5MHz
RX_Master_In
RX_MASTER_IN
64 MHz
LPF Out From PS/VSWR Brd <== TX Conn Brd
Alexiares lpf Modular variable bandpass filter for Hermes/Angelia board Original design by Graham Haddock, KE9H and Phil Harman, VK6APH
May 22nd 2017
HF_TX
7 MHz
20 MHz
40m
60 MHz Bypass
12/10m
To RX HPF board

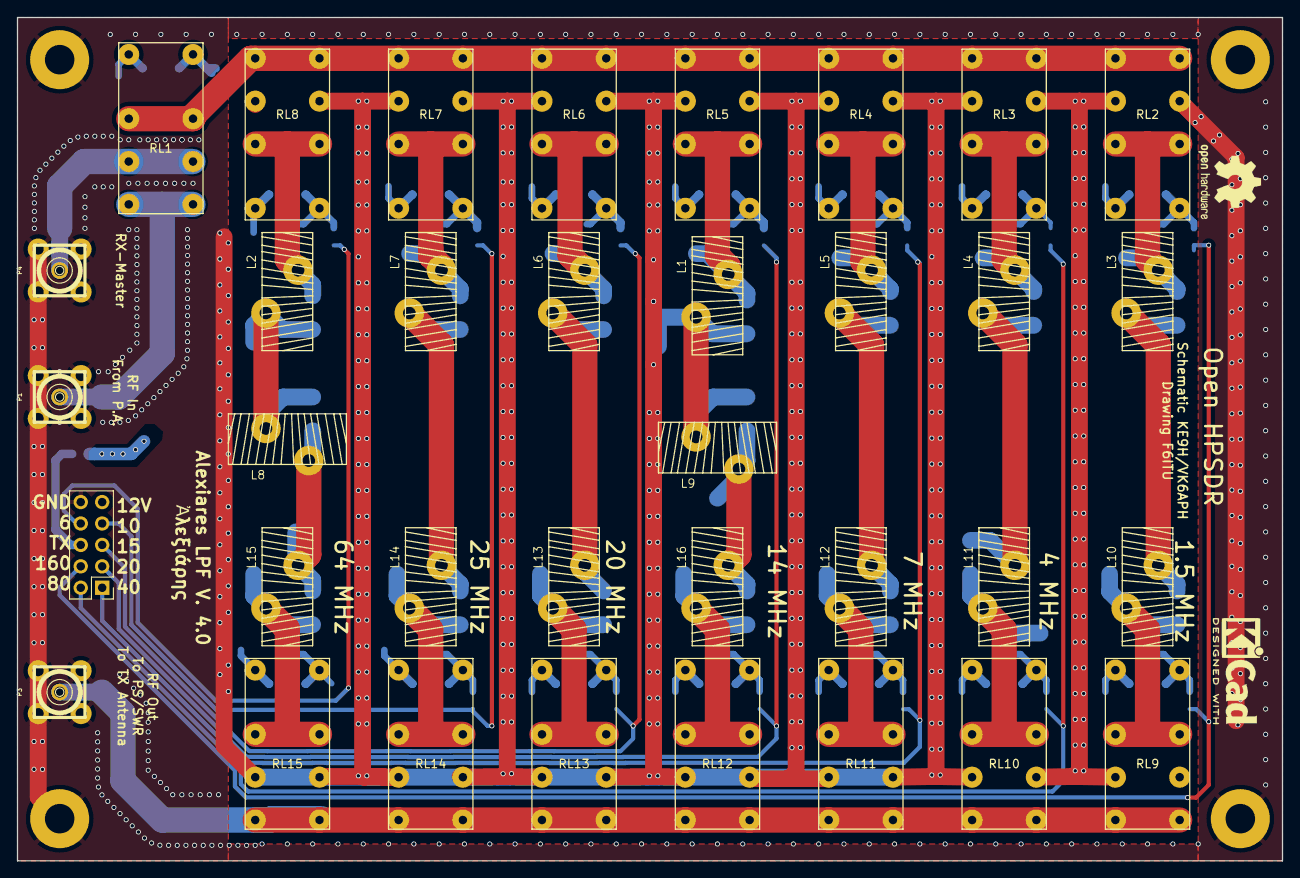
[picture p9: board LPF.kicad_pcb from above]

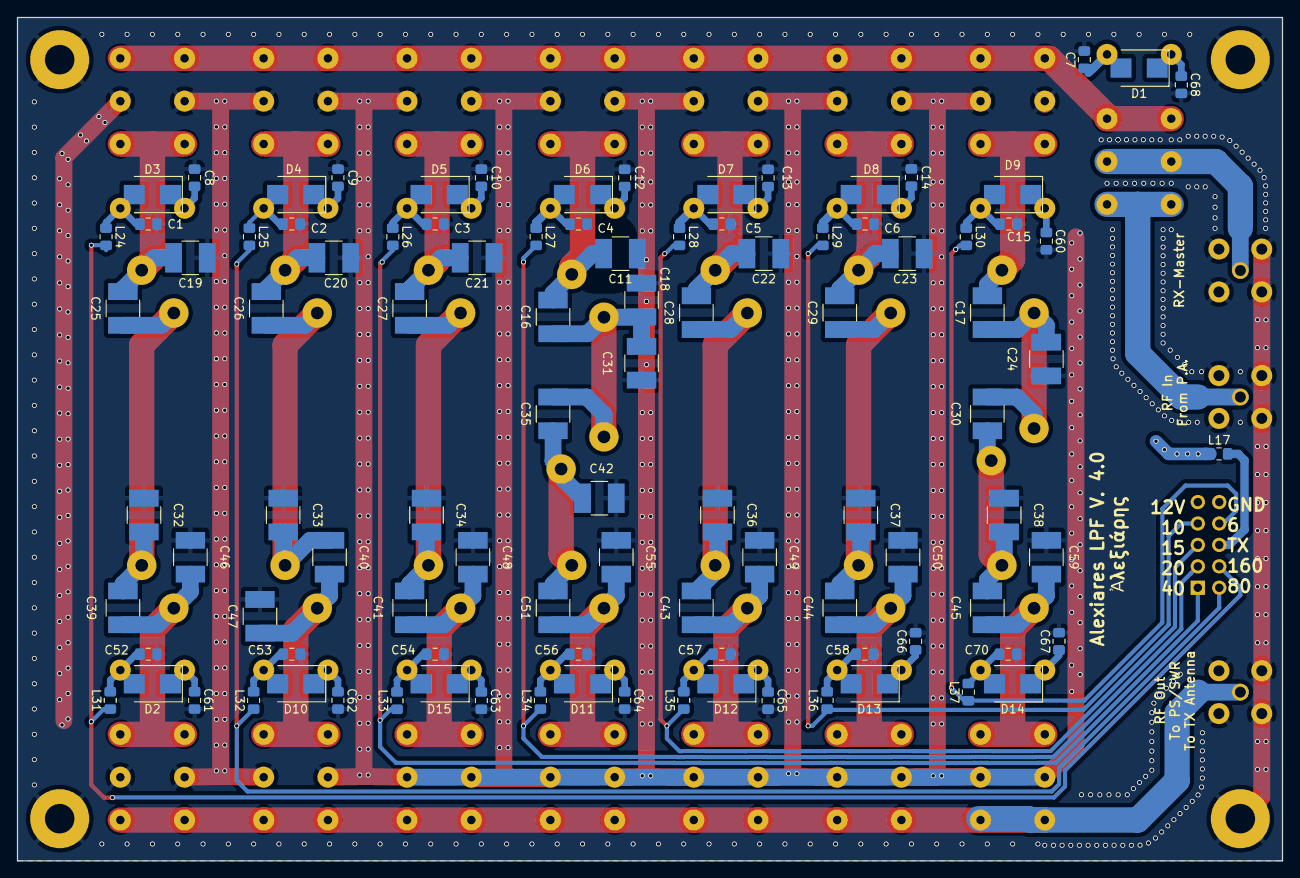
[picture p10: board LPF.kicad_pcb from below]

Board: 4 copper layers, 150.0 x 100.0 mm, 138 parts (99 on the bottom side), 52 nets.

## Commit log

2017-06-12 lpf V1.0, compatible w OpenHPSDR Ver24
    [LPF.kicad_pcb, LPF.sch, cadre.kicad_pcb]
2017-09-14 version 1.1
    [LPF.kicad_pcb, LPF.sch]
2017-11-01 minor changes, adding kk lib, still under dev.
    [LPF.kicad_pcb, LPF.sch]
2017-11-04 new 4 layers routing, mods in schematic
    [LPF.kicad_pcb, LPF.sch, cadre.kicad_pcb]
2017-11-05 decoupling & freewheeling routing
    [LPF.kicad_pcb, LPF.sch]
2017-11-06 RTM 2, silk corrected, via added, jpg image and readme added
    [LPF.kicad_pcb, LPF.sch]
2017-11-10 added choke ferrite on each command line
    [LPF.kicad_pcb, LPF.sch]
2017-11-14 Caps changed for ATC-B footprint. Under dev., unstable
    [LPF.kicad_pcb, LPF.sch]
2017-11-15 new routing after ATC100B change, RTM2
    [LPF.kicad_pcb]
2017-11-27 minor routing changes, via added
    [LPF.kicad_pcb]
2017-12-10 add forbiden zone under bypass power caps
    [LPF.kicad_pcb]
2017-12-12 trace cleaning, SMA edge added, main connector rotated
    [LPF.kicad_pcb, LPF.sch]
2017-12-16 changed sma footprint, gerber done
    [LPF-B.Adhes.gbr, LPF-B.Cu.gbl, LPF-B.Cu.gbr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]
2018-01-05 stitching and new gerber
    [LPF-B.Adhes.gbr, LPF-B.Cu.gbl, LPF-B.Cu.gbr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]
2018-01-06 new stitching, new gerber
    [LPF-B.Cu.gbl, LPF-B.Mask.gbs, LPF-B.SilkS.gbo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]
2018-01-08 stitching errors corrected, new gerber
    [LPF-B.Cu.gbl, LPF-B.Mask.gbs, LPF-B.SilkS.gbo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]
2018-01-09 BOM added, new Gerber
    [Bom ATC_B.xlsx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]
2018-01-12 hunting some last bugs, new gerber
    [Bom ATC_B.xlsx, Bom LPF ATC_B.xlsx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]
2018-01-24 bom changed
    [LPF.CSV]
2018-02-12 hunting smal bugs
    [LPF.kicad_pcb]
2018-02-12 hunting last soldermask errors
    [LPF.kicad_pcb]
2018-05-08 inductance value modified
    [LPF.sch]
2018-06-27 minor silk changes
    [LPF.kicad_pcb, LPF.sch]
2018-06-29 cleaning for V 2.0 version
    [BOM LPF& HPF caps .xlsx, Bom LPF ATC_B.xlsx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]
2018-07-05 minor change in 160m relay position, V2.0 ready
    [LPF-B.Cu.gbl, LPF-B.Mask.gbs, LPF-B.SilkS.gbo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]
2020-07-22 search old and destroy
    [BOM LPF& HPF caps .xlsx, LPF.kicad_pcb, LPF.sch]
2020-07-22 lpf v4.0 file update
    [BOM LPF& HPF caps .xlsx, LPF-2019-03-11-19-05-56.sch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]
2020-07-22 minor cleaning of LPF v4.0 schematic files
    [LPF.sch]
2020-07-22 Excel and csv BOM files added
    [BOM Mouser.xls, LPF.csv, LPF1.csv]
2020-07-22 bom cleaning
    [BOM LPF Mouser.xls, BOM LPF& HPF caps .xlsx, BOM LPF.csv]
2020-07-22 new Excel BOM
    [BOM LPF Mouser grx.xls, BOM LPF Mouser.xls]
2023-04-16 new routing enhancing eddy currents
    [LPF-B_Cu.gbl, LPF-B_Mask.gbs, LPF-B_Paste.gbp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]
2025-08-06 minor changes, 1 bug fixed
    [LPF.kicad_pcb, LPF.kicad_sch]
